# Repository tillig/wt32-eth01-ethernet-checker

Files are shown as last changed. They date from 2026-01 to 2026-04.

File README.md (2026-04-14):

# WT32-ETH01 Ethernet Checker

A standalone tool to verify network connectivity. It checks DHCP, Internet (ICMP), and Web (HTTP) access.

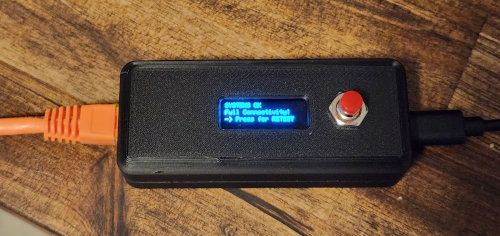
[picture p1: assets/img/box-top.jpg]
The checker in action


When you plug it in, it will test...

- **DHCP:** Verifies network layer and cable integrity.
- **PING:** Verifies routing to the wider internet.
- **HTTP:** Verifies that port 80 traffic isn't blocked by firewalls.

If any of those things fail, it'll tell you which one.

- [Parts](#parts)
- [Hardware Wiring (Production)](#hardware-wiring-production)
- [Hardware Wiring (Programming)](#hardware-wiring-programming)
- [Programming](#programming)
- [Breadboard and Testing](#breadboard-and-testing)
  - [The "Combined" Breadboard Strategy](#the-combined-breadboard-strategy)
  - [Step-by-Step Programming Process](#step-by-step-programming-process)
  - [Transitioning to Testing](#transitioning-to-testing)
  - [Testing the "Production" Power](#testing-the-production-power)
  - [Summary Checklist for Success](#summary-checklist-for-success)
- [Box](#box)
- [References](#references)

## Parts

- [WT32-ETH01](https://amzn.to/4bPwoAS) - $17
- [0.91" I2C IIC 128x32 OLED display](https://amzn.to/3NF82zR) - $12 for 3
- [USB 3.1 female breakout board](https://amzn.to/4mrg90i) - $9 for 10
- [2-pin normally open button](https://amzn.to/4cDuVxz) - $6.50 for 12
- [10K resistor](https://amzn.to/4svy7jM) - $5.50 for a variety pack of 1000

Prices listed are as of this writing. Basically, while there are devices out there that do this same function, they're way more expensive than the parts for this one.

## Hardware Wiring (Production)

| Component | Component Pin | WT32-ETH01 Pin | Note |
| --- | --- | --- | --- |
| OLED | SDA | IO14 | Data |
| OLED | SCK | IO15 | Clock |
| OLED | VCC | 3V3 | Power for display |
| OLED | GND | GND | Ground for display |
| Button | One Pin | IO35 | Push to reset testing |
| Button | One Pin | GND | Push to reset testing |
| 10k Resistor | One Pin | IO35 | Pull-up to keep signal HIGH by default |
| 10k Resistor | One Pin | 3V3 | Pull-up to keep signal HIGH by default |
| USB-C Breakout | VBUS | 5V | Production power input |
| USB-C Breakout | GND | GND | Production power input |

## Hardware Wiring (Programming)

I used [this ESP32 downloader kit from M5Stack](https://shop.m5stack.com/products/esp32-downloader-kit).

Pin connections for USB programmer:

| USB Programmer | WT32-ETH01 |
| --- | --- |
| GND | GND |
| G0 | IO0 |
| EN | EN |
| TXD | RXD |
| RXD | TXD |
| 3.3V | 3V3 |

## Programming

This project is done with [VS Code and PlatformIO](https://docs.platformio.org/en/latest/integration/ide/vscode.html).

1. Set up the ESP32 downloader with your WT32-ETH01.
2. Connect it via USB to your computer.
3. Open in VS Code/PlatformIO and click **Upload**.
4. Remove the downloader and connect the components for standalone USB-C operation.

## Breadboard and Testing

When you're going from "trying things out" to "wired for production" here are some instructions to help get there.

### The "Combined" Breadboard Strategy

All of the components - the production components and the downloader - should all be wired up to the appropriate pins on the WT32 via the breadboard. To keep everything connected safely, follow these rules:

- Shared ground: All components (WT32, OLED, Button, USB-C, and Downloader) must share the same GND rail on your breadboard.
- The power rule: Only connect one 5V source at a time.
- While programming: Plug in the ESP 32 downloader. Leave the USB-C cable unplugged.
- While testing "Production": Unplug the Downloader (or its USB cable) and plug in the USB-C breakout.

### Step-by-Step Programming Process

1. Clone the code from the repo.
2. Plug the ESP32 downloader into your computer (this powers the board).
3. In VS Code, click the "PlatformIO: Upload" icon (the right-pointing arrow) in the bottom status bar.

Watch the terminal. You should see Writing at 0x00001000... and a percentage climb. At the end you should see a "success" message.

### Transitioning to Testing

The WT32-ETH01 does not have a reset button. To run testing, you will have to cycle power (unplug/plug it back into USB power) or push the button we've added as part of the project to start the test again. Note that with the ESP32 downloader, if you unplug/plug it back in, sometimes it does not allow the Ethernet connectivity to work. You may need to use the PlatformIO "Upload" or "Upload and Monitor" functions to reset things and make it run.

Once started, the OLED should light up and display "ETHERNET: Negotiating DHCP..."

Plug in an Ethernet cable.

Watch the progress bar. If it hits "SYSTEMS OK," your hardware and software are verified.

### Testing the "Production" Power

Now, let's verify your USB-C breakout works for the final build:

1. Unplug the ESP32 downloader's USB cable from your computer.
2. Ensure your USB-C breakout is wired to the 5V and GND rails.
3. Plug a USB-C cable into the breakout.
4. The device should spring to life exactly as it did with the downloader.

Press your physical button on IO35. The screen should clear and restart the test sequence.

### Summary Checklist for Success

- Flash Mode: IO0 -> GND + Reset.
- Run Mode: IO0 -> Disconnected + Reset.
- Wiring Check: Is the 10k resistor definitely going to 3.3V (not 5V)? IO35 is not 5V tolerant for long periods.
- Ethernet: Ensure your WT32-ETH01 is getting enough current. If the OLED flickers when Ethernet initializes, your USB port might not be outputting enough milliamps (Ethernet is power-hungry on ESP32).

## Box

I [provided the .3mf file and instructions](./assets/box/README.md) for the box I made to hold this. It should work well for you if you used the same parts as I did.

## References

- [Unofficial Guide to the WT32-ETH01](https://github.com/egnor/wt32-eth01)
- [How to Use wt32-eth01: Examples, Pinouts, and Specs](https://docs.cirkitdesigner.com/component/19888585-1942-4683-b24c-de1a4e53a293/wt32-eth01)
- [Getting Started with VS Code and PlatformIO IDE for ESP32 and ESP8266](https://randomnerdtutorials.com/vs-code-platformio-ide-esp32-esp8266-arduino/)

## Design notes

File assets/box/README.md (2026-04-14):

# Ethernet Checker Box

If you used the same parts as I did, this box should work pretty well for you.

You'll need:

- (6) M2x4 self-tapping screws
- (2) M3x4 self-tapping screws

Print the box with the large faces down. No supports are required.

- Use two of the M2x4 screws to mount the WT32-ETH01 to the standoffs near the end of the case bottom with the opening for the Ethernet jack.
- Use four of the M2x4 screws to mount the OLED display to the inside of the lid.
- Use the two M3x4 screws to mount the USB-C breakout board to the standoffs near the end of the case bottom with the opening for the USB-C port.

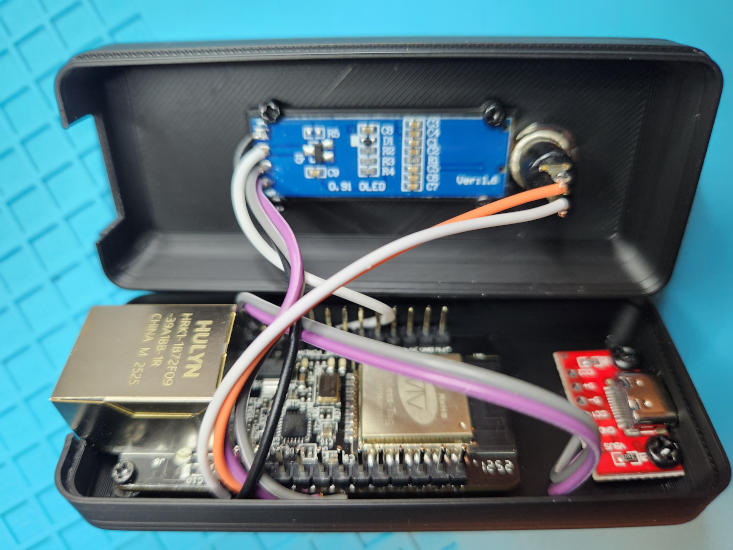
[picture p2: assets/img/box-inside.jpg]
Inside of box showing mounting positions


The box snaps together, but you may want a couple of dots of superglue to keep it in place. It's not that tight of a fit. Once you're done, it should look pretty decent.

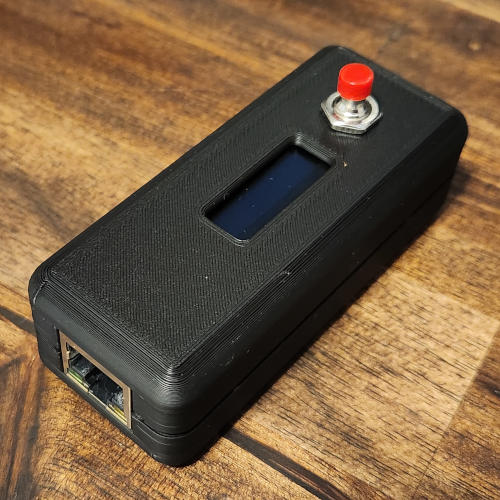
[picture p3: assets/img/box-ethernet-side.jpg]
Side of box showing Ethernet


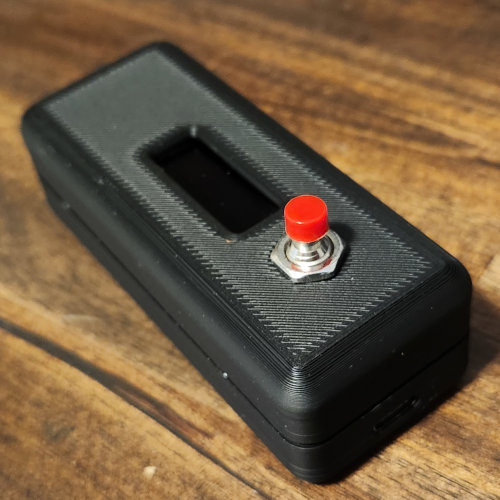
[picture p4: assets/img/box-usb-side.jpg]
Side of box showing USB-C


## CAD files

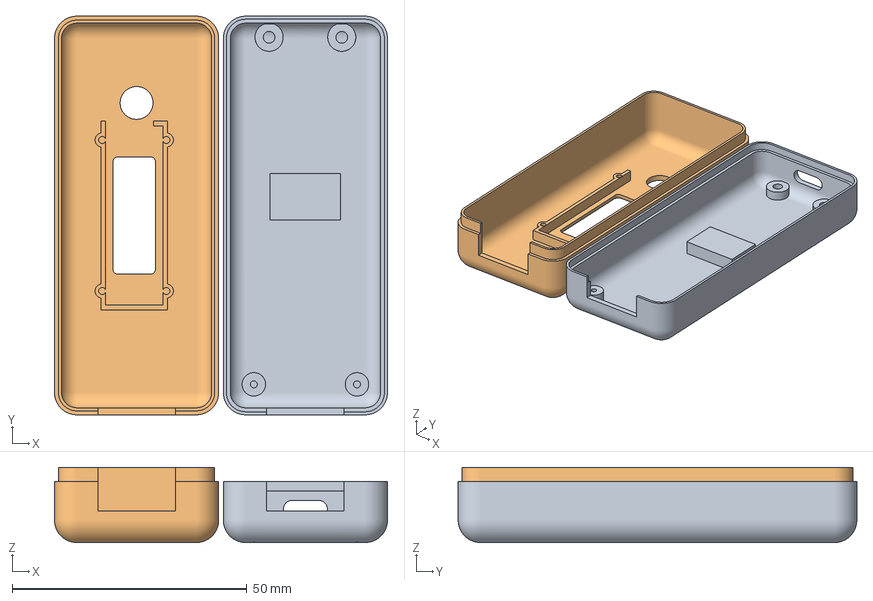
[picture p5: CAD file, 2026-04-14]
assets/box/ethernet-checker-box.3mf
71.0 x 85.0 x 16.0 mm
Box Bottom.obj
Box Top.obj

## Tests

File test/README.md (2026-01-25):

# Test Folder

This directory is intended for PlatformIO Test Runner and project tests.

Unit Testing is a software testing method by which individual units of source code, sets of one or more MCU program modules together with associated control data, usage procedures, and operating procedures, are tested to determine whether they are fit for use. Unit testing finds problems early in the development cycle.

[More information about PlatformIO Unit Testing.](https://docs.platformio.org/en/latest/advanced/unit-testing/index.html)

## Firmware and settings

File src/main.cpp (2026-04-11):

#include <Arduino.h>
#include <ETH.h>
#include <ESP32Ping.h>
#include <HTTPClient.h>
#include <Adafruit_SSD1306.h>

#define SCREEN_WIDTH 128
#define SCREEN_HEIGHT 32
#define BUTTON_PIN 35

Adafruit_SSD1306 display(SCREEN_WIDTH, SCREEN_HEIGHT, &Wire, -1);

/**
 * @brief Logs status updates to Serial Monitor and OLED display.
 * @param title The title of the status update.
 * @param detail The details of the status update.
 * @param progress The progress percentage.
 * @param isEndState Whether this is the final state of the test (and we're waiting for a button press to restart).
 */
void logStatus(String title, String detail, int progress, bool isEndState = false)
{
  // Output to Serial Monitor for debugging
  Serial.println("-------------------------");
  Serial.println("STATUS: " + title);
  Serial.println("DETAIL: " + detail);
  Serial.println("PROGRESS: " + String(progress) + "%");

  // Output to OLED
  display.clearDisplay();
  display.setTextSize(1);
  display.setTextColor(SSD1306_WHITE);

  display.setCursor(0, 0);
  display.println(title);
  display.setCursor(0, 12);
  display.println(detail);

  if (isEndState)
  {
    Serial.println("WAITING FOR BUTTON PRESS...");
    display.setCursor(0, 24);
    display.print("-> Press for RETEST");
  }
  else
  {
    int barWidth = map(progress, 0, 100, 0, 128);
    display.fillRect(0, 28, barWidth, 4, SSD1306_WHITE);
  }

  display.display();
}

/**
 * @brief Runs the Ethernet connectivity check.
 */
void runEthernetCheck()
{
  Serial.println("\n*** STARTING ETHERNET TEST ***");

  // Stage 1: DHCP
  logStatus("ETHERNET", "Negotiating DHCP...", 20);
  unsigned long start = millis();
  while (!ETH.linkUp() || ETH.localIP().toString() == "0.0.0.0")
  {
    if (millis() - start > 12000)
    {
      logStatus("DHCP FAIL", "No IP received.", 0, true);
      return;
    }

    delay(100);
  }

  // Stage 2: Ping
  logStatus("IP: " + ETH.localIP().toString(), "Pinging 8.8.8.8...", 60);
  if (!Ping.ping("8.8.8.8", 2))
  {
    logStatus("PING FAIL", "Google Unreachable", 0, true);
    return;
  }

  // Stage 3: HTTP
  logStatus("PING OK", "Checking HTTP...", 85);
  HTTPClient http;
  http.begin("http://connectivitycheck.gstatic.com/generate_204");
  int httpCode = http.GET();

  if (httpCode > 0)
  {
    logStatus("SYSTEMS OK", "Full Connectivity!", 100, true);
  }
  else
  {
    logStatus("HTTP FAIL", "Error: " + String(httpCode), 0, true);
  }

  http.end();
}

/**
 * @brief Initializes the WT32-ETH01 checker.
 */
void setup()
{
  Serial.begin(115200);
  delay(500); // Wait for serial monitor to open
  Serial.println("\n[BOOT] WT32-ETH01 checker starting...");

  pinMode(BUTTON_PIN, INPUT); // External 10k Pull-up used
  Serial.println("[BOOT] GPIO 35 input initialized.");
  // Wire.begin(SDA, SCL);
  Wire.begin(14, 15);

  if (!display.begin(SSD1306_SWITCHCAPVCC, 0x3C))
  {
    Serial.println("[WARN] OLED not found. Check IO14/IO15. Continuing in Serial-only mode.");
  }
  else
  {
    Serial.println("[INFO] OLED initialized.");
  }

  Serial.println("[INFO] Starting Ethernet PHY...");
  ETH.begin();
  runEthernetCheck();
}

/**
 * @brief Main loop checks for button press to restart the test.
 */
void loop()
{
  // Manual Trigger: Check if IO35 is pulled LOW (button pressed)
  if (digitalRead(BUTTON_PIN) == LOW)
  {
    delay(50); // Debounce
    if (digitalRead(BUTTON_PIN) == LOW)
    {
      Serial.println("[USER] Button pressed. Restarting test.");
      while (digitalRead(BUTTON_PIN) == LOW)
        ; // Wait for release
      runEthernetCheck();
    }
  }
}

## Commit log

2026-04-11 Fix typo on pin name.
2026-04-14 Added 3D model for box.
    [ethernet-checker-box.3mf]
